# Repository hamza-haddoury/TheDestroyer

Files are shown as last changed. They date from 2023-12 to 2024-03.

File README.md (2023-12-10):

Logo Polytech Nice Sophia

# TheDestroyer
TheDestroyer est un projet Arduino réalisé dans le cadre de la formation de prépa intégrée de Polytech Nice-Sophia.
## Présentation
TheDestroyer est un tank miniature capable de se mouvoir et de tirer des projectiles.( voir le <a href="/Documentation/Cahier-des-charges.pdf">cahier des charges</a> )

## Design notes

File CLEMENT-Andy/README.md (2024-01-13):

# Dossier personnel de CLEMENT Andy sur le projet TheDestroyer
Vous trouverez ici le planning ainsi que les rapports de séance personnels concernant le projet Arduino.

## Planning 
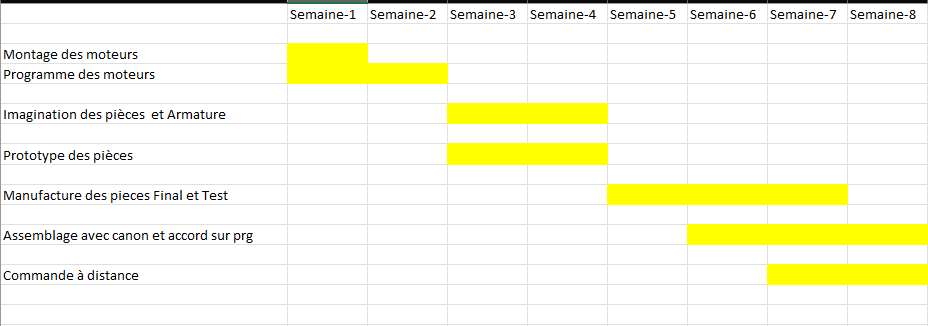
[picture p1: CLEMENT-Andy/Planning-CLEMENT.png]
Planning de CLEMENT Andy


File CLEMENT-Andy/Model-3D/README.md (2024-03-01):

<p>Vous trouverez les modèles 3D qui ont servi à la conception du tank.<br/>
Vous trouverez <a href="https://cad.onshape.com/documents/29475f88cb30b432ccc1cab9/w/a2ebf4db9098ca263dcf5bed/e/63d1c44178a9f2d052091fa9"> ici </a> le lien de partage Onshape qui vous permez de voir mon travail.</p>

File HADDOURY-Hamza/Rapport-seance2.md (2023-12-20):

L'objectif de la séance d'aujourd'hui était de modéliser les roues qui seront fixées sur les deux moteurs, de mettre à niveau l'alimentation des moteurs avec une source 5V dédiée, résoudre le problème lié à la vitesse d'un des moteurs et travailler sur la modélisation 3D de la partie supérieure du canon, capable de pivoter.

---

## Modélisation des Roues 

- Modélisationn des roues sur Onshape, conçues pour propulser la balle à travers le canon avec un espace dédié aux joints qui seront en contact avec la balle.
Mon Image

---

## Résolution des Problèmes de Moteurs :

- Un des moteurs ne tournait pas à plein régime comme le second.
- La résolution a été apportée en ajustant les connexions électriques et en recalibrant le code de contrôle des moteurs.

---

## Ajustements dans le Code Arduino 

- Des modifications ont été apportées dans le code Arduino pour garantir un contrôle équilibré et optimal des deux moteurs.

---

## Avancées sur la Modélisation 3D du Canon 

- Travail en cours sur la modélisation 3D de la partie supérieure du canon, qui aura la capacité de pivoter.

---

## Mise à Niveau de l'Alimentation 

- Pendant la séance, une alimentation 5V dédiée a été introduite pour les moteurs.
- Cette mise à niveau a été effectuée pour fournir le courant nécessaire aux moteurs afin de leur permettre de tourner à plein régime, comblant ainsi la limitation de courant de la carte Arduino.

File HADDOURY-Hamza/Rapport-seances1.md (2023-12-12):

### • Matériel recue
2 moteurs pour tirer les projectiles  
2 servomoteurs pour controler l'orientation du canon  

### • Montage Arduino
Attribution des broches appropriées de l'Arduino pour le contrôle des moteurs, avec un pont en H (L298N) pour gérer la polarité et la vitesse.  

Mon Image

### • Code de Contrôle des Moteurs
Développement d'un code Arduino permettant un contrôle de la vitesse (puissance de tir).

```
int enableMotor1 = 9;   

int motor1Input1 = 8;    
int motor1Input2 = 7;    

int enableMotor2 = 10;    
int motor2Input1 = 11; 
int motor2Input2 = 12; 

void setup() {
  // Configuration des broches en sortie
  pinMode(enableMotor1, OUTPUT);
  pinMode(motor1Input1, OUTPUT);
  pinMode(motor1Input2, OUTPUT);

  pinMode(enableMotor2, OUTPUT);
  pinMode(motor2Input1, OUTPUT);
  pinMode(motor2Input2, OUTPUT);
}

void loop() {
  analogWrite(enableMotor1, 200); 
  digitalWrite(motor1Input1, HIGH);
  digitalWrite(motor1Input2, LOW);

  analogWrite(enableMotor2, 150); // Valeur entre 0 (arrêt) et 255 (vitesse maximale)
  digitalWrite(motor2Input1, HIGH);
  digitalWrite(motor2Input2, LOW);

  delay(5000);

  // Arrêt des moteurs
  digitalWrite(motor1Input1, LOW);
  digitalWrite(motor1Input2, LOW);
  digitalWrite(motor2Input1, LOW);
  digitalWrite(motor2Input2, LOW);

  delay(2000);
}

```

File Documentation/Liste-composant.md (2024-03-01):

# Liste des composants éléctroniques utilisés: 
<ul>
<li>1 Carte Arduino Mega</li>
<li>2 motoréducteurs à courant continue</li>
<li>2 ponts en H ( L298N) </li>
<li>1 module Blutooth HC-05</li>
<li>1 batterie Lithium-ion de 7V</li>
<li>3 servos moteurs</li>
<li>2 moteurs à faible couple</li>
</ul>

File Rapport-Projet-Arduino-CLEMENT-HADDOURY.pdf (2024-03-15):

CLÉMENT Andy/
HADDOURY Hamza

# Rapport Projet Arduino: The Destroyer

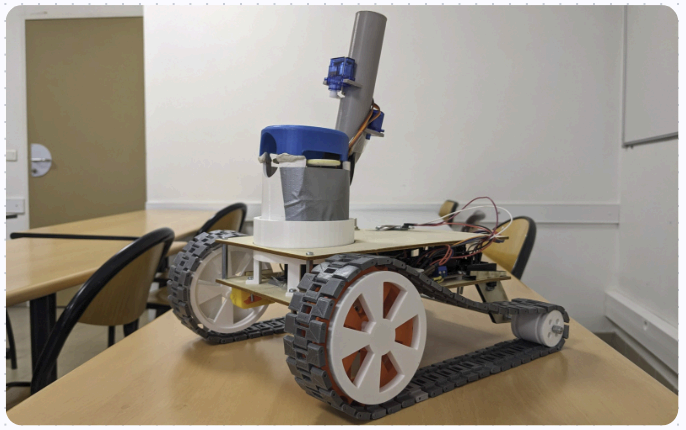
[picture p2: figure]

## Introduction

Ce projet à été réalisé dans le cadre de la formation de prépa intégrée de Polytech Nice-Sophia. Le but était de créer en 8 semaines un objet en utilisant des composants électroniques pilotables via une carte Arduino. Ce projet est une mise en situation (dans une moindre mesure) du métier d'ingénieur et permet donc de nous projeter dans notre futur métier. Pour le choix du sujet, nous voulions un objet qui se rapproche d’un jouet, il devait être simple d’utilisation et amusant, il nous est alors venue l’idée d’un tank télécommandable.

The Destroyer est un tank capable de se déplacer dans toutes les directions et tirer des balles en mousse via son canon intégré. Le tank est commandable à distance via une télécommande bluetooth ( ici notre téléphone portable) et fonctionne sur une batterie. Les commandes doivent être réactives pour assurer un contrôle en temps réel.
Pour créer un tel objet il nous fallait respecter quelques points.

Mobilité
- Intégrer deux moteurs pour entraîner les chenilles, se sont des roues motrices.
- Programmer les mouvements du tank (avancer, reculer, tourner).
Canon
Orientation du Canon:
- Intégrer un servo-moteur pour piloter l'orientation du canon.
- Programmer le contrôle de l'orientation via la télécommande. Fonctionnalité de Tir:
- Intégrer un mécanisme de tir (par exemple, un lanceur de projectiles).

- Programmer le contrôle du tir via la télécommande.

Alimentation
Batterie rechargeable assurant l'alimentation général du tank.

Châssis et chenille
- Concevoir et construire un châssis robuste pour protéger et transporter les composants.
- Imaginer les maillons de chenilles pour assurer la mobilité.
- Intégrer des phares LED pour une meilleure visibilité dans des conditions de faible luminosité.

Logement des éléments:
- Intégrer un support solide pour le canon, permettant une orientation précise.
- Prévoir un espace dédié pour la carte Arduino et les différents composants présents.
- Concevoir un compartiment pour la batterie, avec un accès facile pour la recharge.

Commande à distance
- Associer le code du véhicule avec un moyen de contrôle à distance ( Par Bluetooth)

## Notice d'utilisation

Le tank dispose d’un interrupteur pour la mise en marche et l’arrêt. Une fois allumé il faut associer le véhicule à la télécommande (smartphone utilisant l’application bluetooth electronics). Vous pouvez désormais diriger le tank à votre envie !

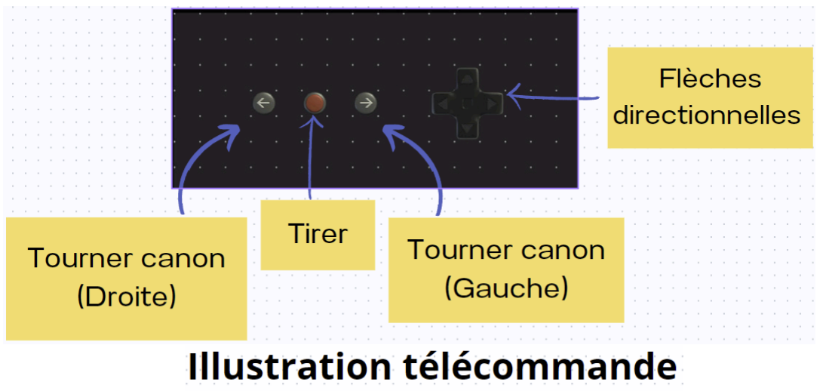
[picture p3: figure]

## Schéma électrique

Pour que le tank fonctionne correctement il a fallu câbler chaque composant correctement pour éviter toute panne. En effet les motoréducteurs et les moteurs à faible couple doivent être alimentés en 6V via des ponts en H qui sont eux-même alimentés via deux alimentations différentes, une servant à alimenter les portes logiques (5V) et une autre alimentant les moteurs ( allant jusqu'à 12V). La batterie ayant une tension de 7.46V, il nous était nécessaire d’avoir un contrôleur de tension pour avoir une tension de 6V dans le circuit. Tous les autres composants sont alimentés via la carte Arduino. On a donc deux circuits d’alimentation, une pour les ponts en H, une autre pour le reste des composants.

En somme le circuit contient:
1 Carte Arduino Mega, 2 motoréducteurs à courant continu, 2 ponts en H ( L298N), 1 module Bluetooth HC-05,1 batterie Lithium-ion de 7V, 1 Contrôleur de tension, 3 servomoteurs- SG90 (Chargeur), 2 moteurs à faible couple-MABUCHI RS 280 ( lanceur de balle).

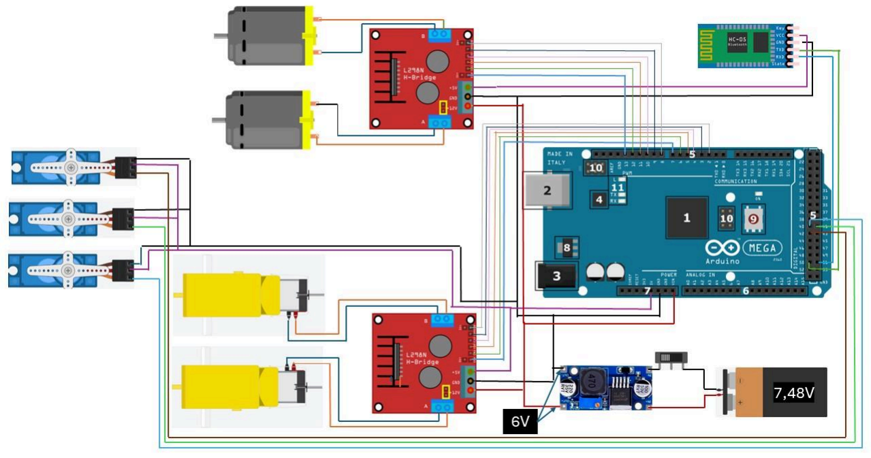
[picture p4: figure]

## Algorigramme

Chaque action du tank est reliée à une fonction pour simplifier l’écriture du programme. Chaque fonction est lancée si le caractère auquel il est associé est lu dans le buffer. Les caractères sont reliés à un bouton particulier sur la télécommande et sont envoyés à la carte si l’on appuie sur le bouton correspondant. ( à noter que les boutons associés à la direction renvoient ‘/’ s’il ne sont pas actionnés). L’algorithme est structuré comme tel:

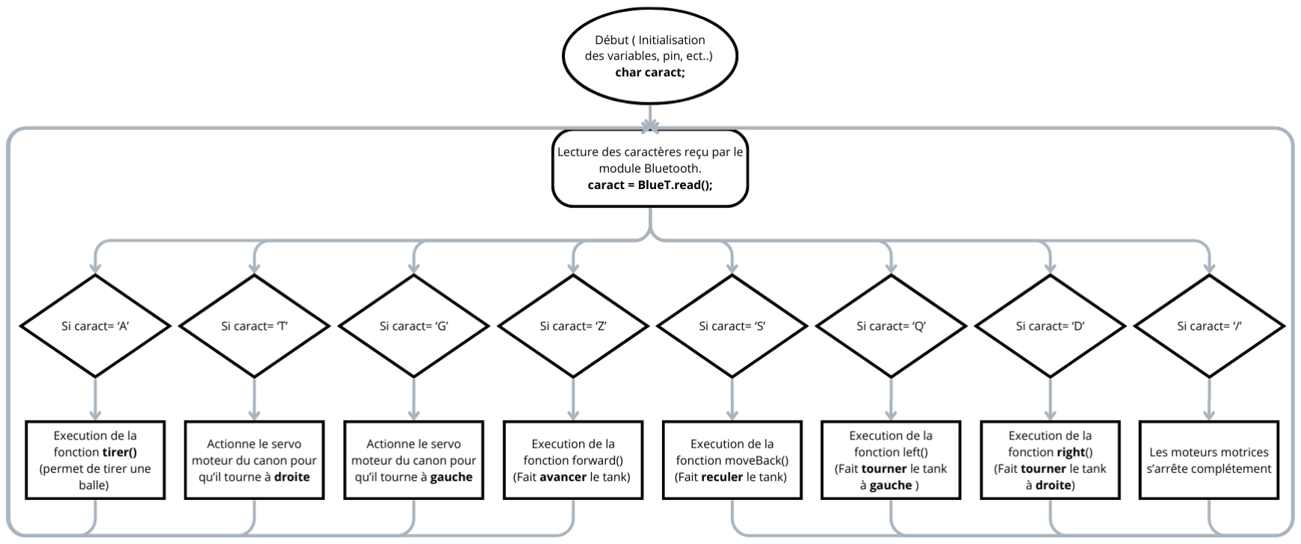
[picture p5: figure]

Toutes les fonctions mentionnées contrôlent la direction de rotation des moteurs ainsi que la puissance attribuée à chacun durant l’action. A noter que le programme n’utilise pas de ‘if()’ pour décider de quelle fonction appeler mais utilise les instructions ‘switch()’ et ‘case’.

## Coût du projet

Pour estimer le coût de construction du projet nous comptons les coûts d’achat du matériel ( Carte arduino, batterie, moteurs, bois, ect..) ainsi que le nombre d'heures de travail effectué sur le projet. Pour calculer le coût du travail nous sommes partis sur la base d’un salaire brut annuel de 38k € pour 1600h de travail ( 23.75€/ 1h) . En comptant les 8 séances dédiées au projet et le travail personnel , nous sommes à (38 h+30 h = 68 h) heures de travail, ce qui nous revient à 1615€ pour le coût de la main d'œuvre. Pour le coût du matériel, nous avons cherché les prix sur Amazon ou encore AliExpress. Nous avons essayé de prendre les prix les plus bas pour limiter les coûts( voir le détail des prix en dessous). Au final le projet à coûté 1678.5€.

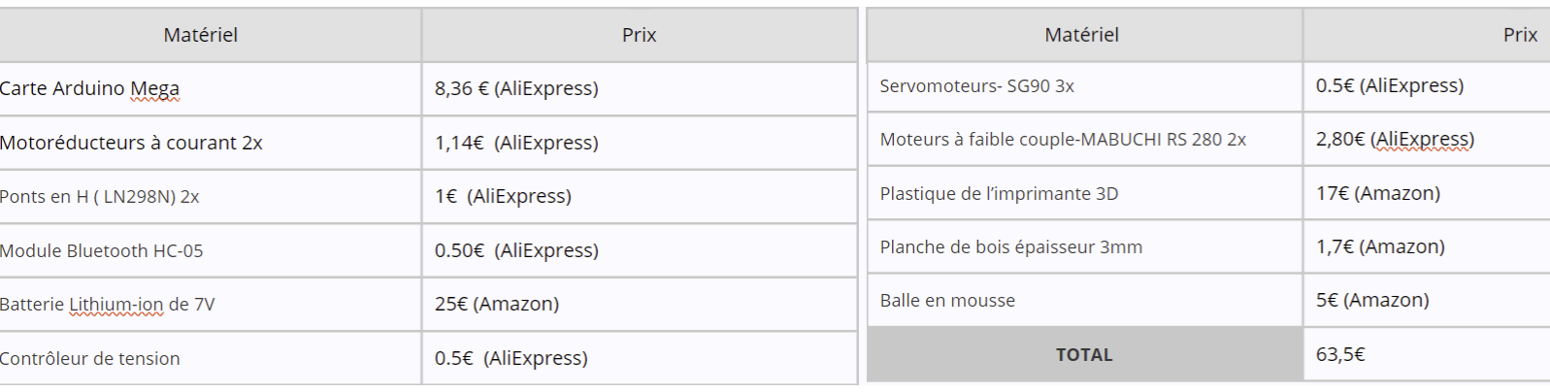
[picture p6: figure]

## Problèmes rencontrés

Problème Châssis et chenille:

Lors des essais de roulage, les chenilles sortaient de leur trajectoire et déraillaient. Ce problème était dû aux chaînes qui n'étaient pas assez tendues parce que les roues arrière s'affaissaient à cause du poids trop important du tank, de plus les roues motrices du tank avaient également un carrossage négatif ce qui empêchait les chenilles de maintenir une trajectoire droite. Pour régler ce problème, nous avons décidé d’ajouter une tige filetée entre les deux supports de roue arrière pour éviter que les roues ne s’affaissent. Pour les roues avant nous avons ajouté de la pâte à fixe pour combler le jeu entre le châssis et les moteurs.

On a également dû changer de type de cartes passant d’une carte Uno à une carte Mega. Puisque nous avions besoin de deux ponts en H ( L298N), nous avions besoin de plusieurs ports PWM, malheureusement, la carte Uno n’en possédait pas assez, c’est pourquoi nous sommes passés sur une carte Mega.

Problèmes Canon:

Lors des phases d'essai, nous avons identifié un problème majeur lié au chargement manuel des balles entre les moteurs du canon. Nous avons constaté que cette opération devait être effectuée manuellement à chaque fois qu'un tir était envisagé. De plus, le fait que la balle ne pouvait pas rester en place entre les moteurs en attente d'être tirée était un inconvénient majeur. Les moteurs manquaient de couple pour maintenir la balle en place, ce qui entraînait un blocage.

Pour remédier à cette problématique, nous avons élaboré un système de recharge. En activant la commande de tir, notre système de chargeur permet désormais le passage automatique d'une balle entre les moteurs du canon. Cette amélioration nous permet de tirer jusqu'à cinq balles consécutivement sans avoir besoin d'une intervention manuelle pour charger chaque projectile.

Après l’assemblage avec le châssis, les moteurs chargés de propulser la balle consommaient excessivement de courant, laissant peu de ressources aux moteurs du chargeur. Cette situation a entraîné plusieurs dysfonctionnements et bugs, dans certains cas après avoir été activés les moteurs ne s'arrêtaient plus, compromettant ainsi le bon fonctionnement global du système.

De plus, lors de la sortie de la balle du chargeur en vue de son tir, des incidents se sont produits. Parfois, la balle rebondissait, échappant ainsi à l'axe des roues du moteur destiné à la propulsion. Dans certains cas, elle était éjectée sans être correctement projetée, tandis que dans d'autres, elle restait coincée, bloquant les balles suivantes.

## Planning

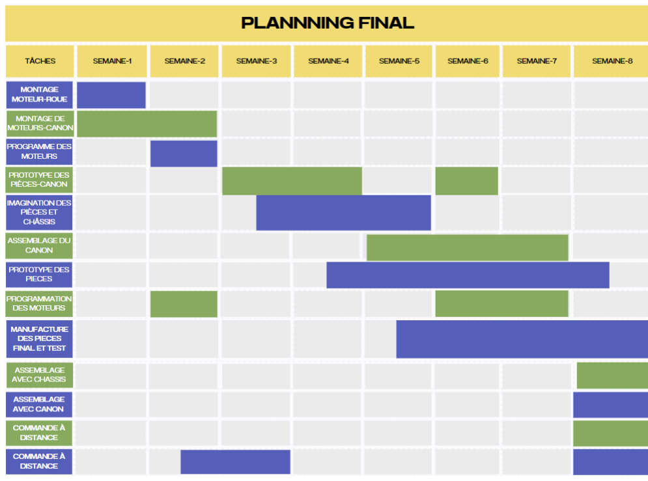
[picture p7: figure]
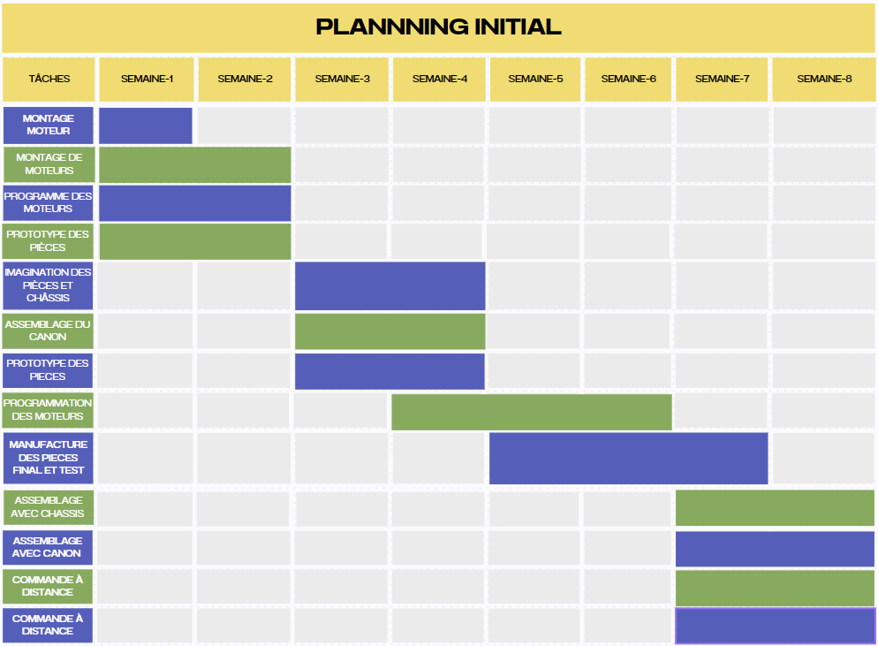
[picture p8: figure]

Avant de commencer le projet, nous avions créé un planning ( diagramme de Gantt) qui organisait notre travail et ainsi assurait que l’on rend le projet à temps et fonctionnel. Initialement nous avions défini découpé et attribué une période chaque phase du projet, cependant durant le projet, on s’est aperçu que certaines tâches demandaient plus de temps que prévu. En comparant les deux emplois du temps, on se rend compte que les tâches effectuées en début de cycle respectaient bien le temps prévu mais que certaines tâches ont demandé plus de temps que prévu. La conception et la réalisation des pièces ont demandé plus d’effort que prévu ce qui a empiété sur le temps consacré à l’assemblage.

## Conclusion

En conclusion sur ce projet nous avons produit un châssis pouvant accueillir des composants électroniques ainsi qu’un capot en bois sur mesure, des roues crantées adaptées aux motoréducteurs pour entraîner les chenilles, un système de direction et des commandes simples d’utilisation. Pour le canon, nous avons développé un mécanisme de tir permettant de tirer jusqu'à cinq balles coup par coup sans nécessiter d'intervention manuelle entre chaque tir, grâce à un système de rechargement automatique. De plus, le canon est également doté d'une capacité d'orientation. Les phares initialement prévus n’ont pas été intégrés par faute de temps.

Si nous avions encore 9 séances supplémentaires, nous développerions la partie esthétique du tank en peignant les pièces et en concevant un revêtement travaillé et agréable à l'œil. Nous pourrions intégrer les phares comme initialement prévu pour avoir une bonne vision la nuit et peut-être même ajouter une caméra embarquée qui nous transmettra en temps réel les images perçues. On pourrait également développer une application exportant la possibilité de contrôler le tank via d'autres périphériques ( Iphone ou encore PC) car actuellement, seulement un smartphone android peut le piloter.

Ce projet nous a permis de nous mettre en situation et de nous projeter dans le métier d’ingénieur. Il nous a également appris à faire preuve d'inventivité, d’esprit d’équipe et nous a poussé à chercher des solutions pour régler les différents problèmes rencontrés.

## Bibliographie

Site d’aide au montage:

https://www.adafruit.com/product/3777https://arduino-france.site/moteur-cc/https://docs.arduino.cc/learn/built-in-libraries/software-serial/https://arduino-france.si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

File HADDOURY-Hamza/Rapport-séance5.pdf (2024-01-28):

## Rapport séance 5

Objectifs de la Séance:
L'objectif principal de la séance était de modéliser les différentes pièces du canon. Ces pièces comprennent le support du cylindre pour les moteurs, le cylindre lui-même, le support des moteurs à l'intérieur du cylindre, et enfin le canon.

Support du cylindre :

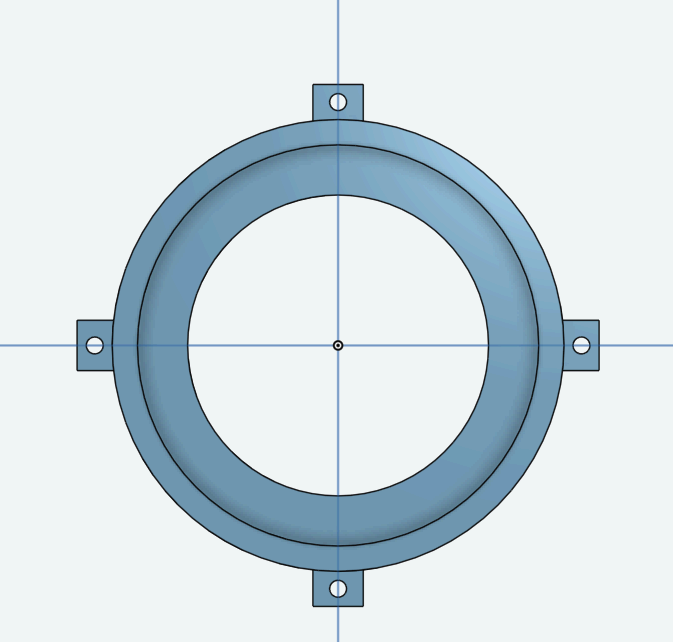
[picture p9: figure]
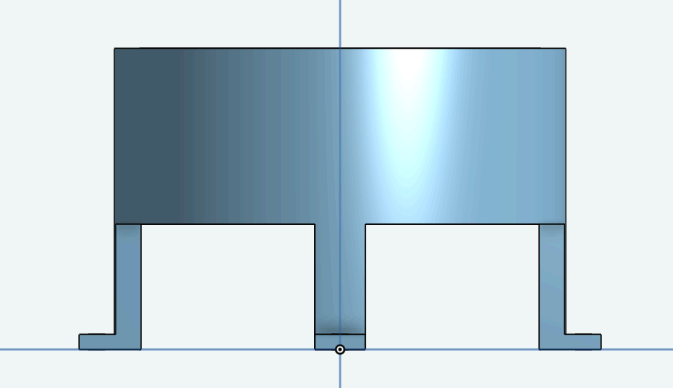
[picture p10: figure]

vue de face | vue de haut

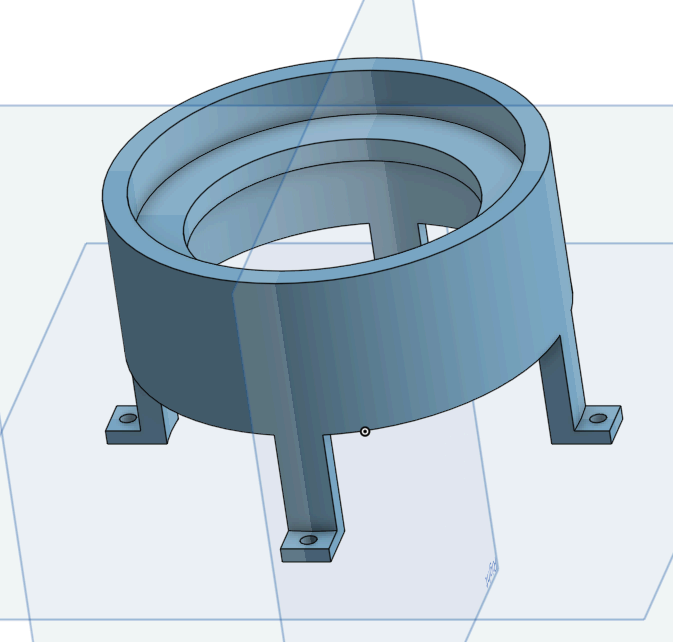
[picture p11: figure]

Le support sera fixé au châssis et à l'intérieur de lui se trouvera le servo moteur pour orienter le cylindre.

Cylindre et canon :

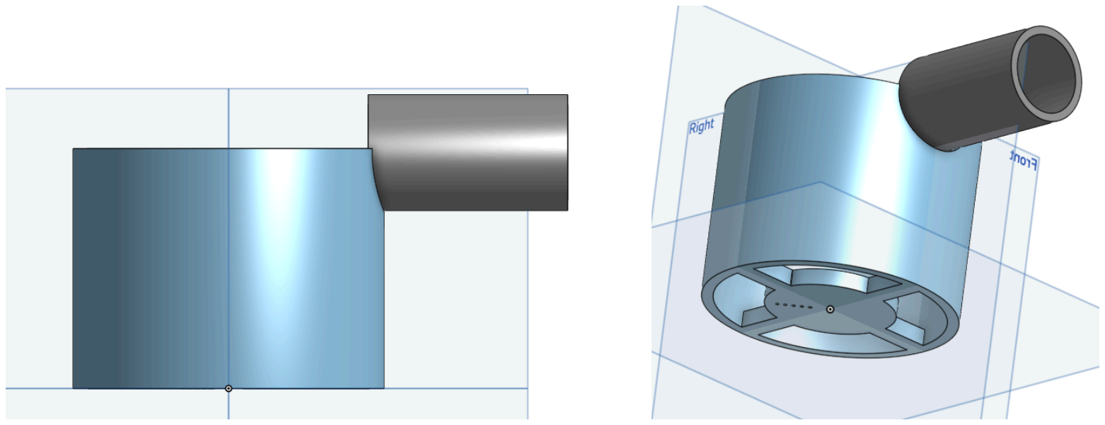
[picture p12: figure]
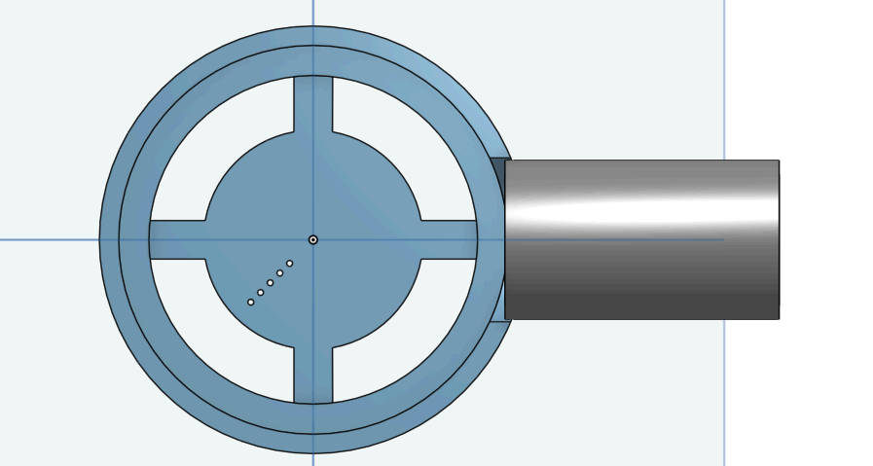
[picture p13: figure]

vue de haut | vu de face

Le cylindre sera fixé au servomoteur et abritera les deux moteurs qui propulseront le projectile à travers le canon.

Support des moteurs

pour réaliser cette pièce je me suis inspiré de la maquette en carton que j’ai faite pendant la séance 4

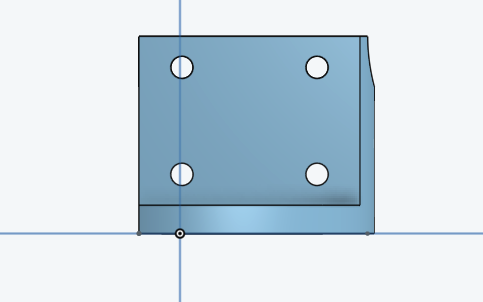
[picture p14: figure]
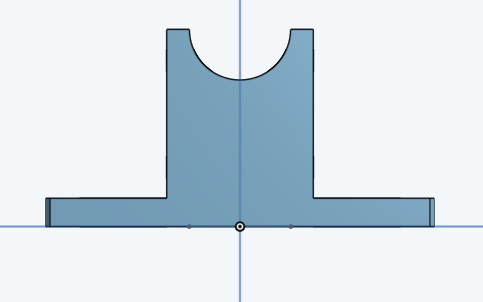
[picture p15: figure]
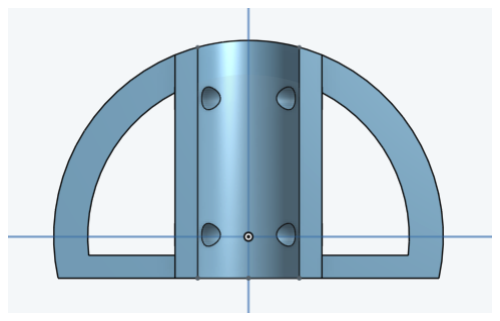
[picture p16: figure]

vue de haut | vue de face | vue de droite

Assemblage de toute les pièces

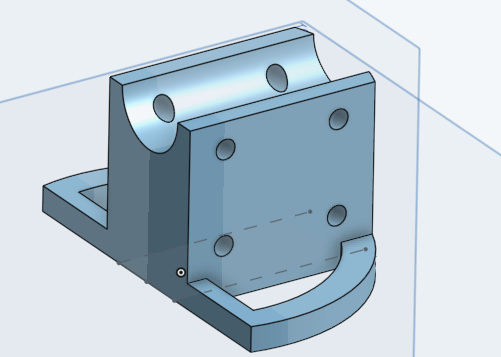
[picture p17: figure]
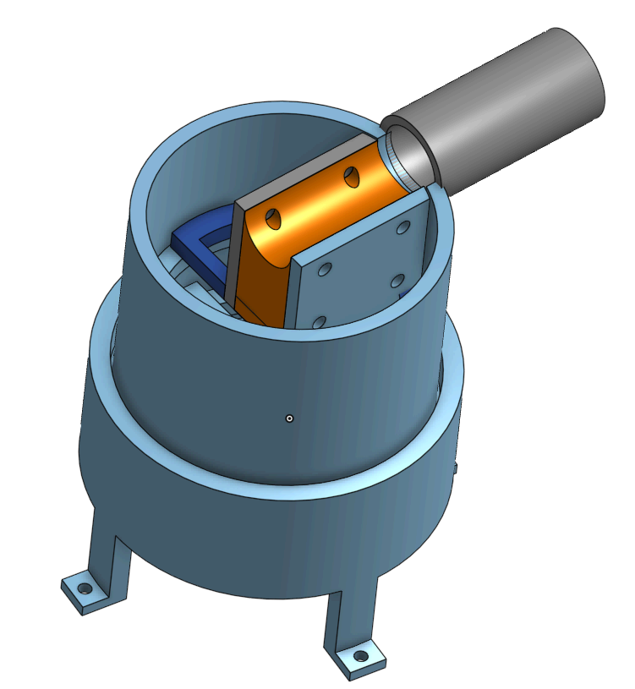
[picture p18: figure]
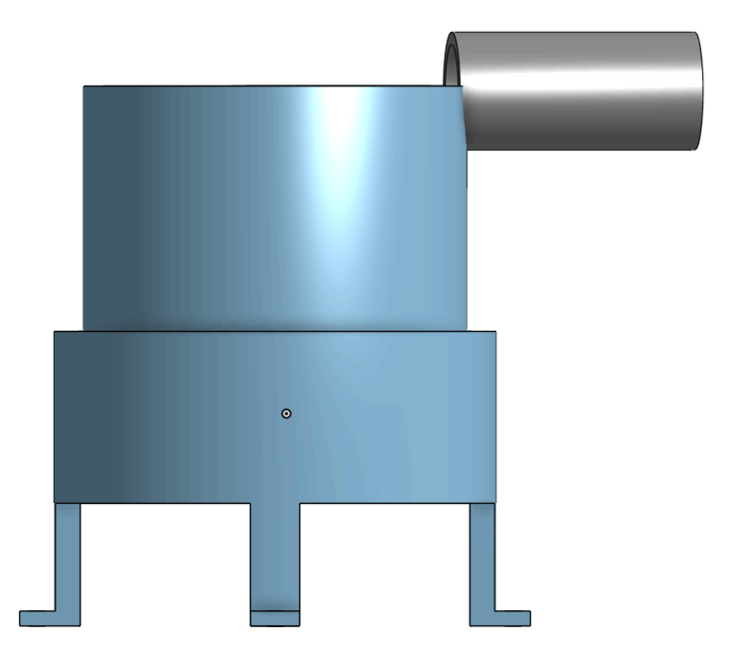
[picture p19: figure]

Malheureusement durant cette séance je n’ai pu imprimer que le support des canons par manque de temps. En y fixant les moteurs, j’ai réalisé que mes mesures n'étaient pas assez précise car l’espace entre les roues des moteurs était assez important et ne permettait aucun frottement avec la balle afin d'être projeté.

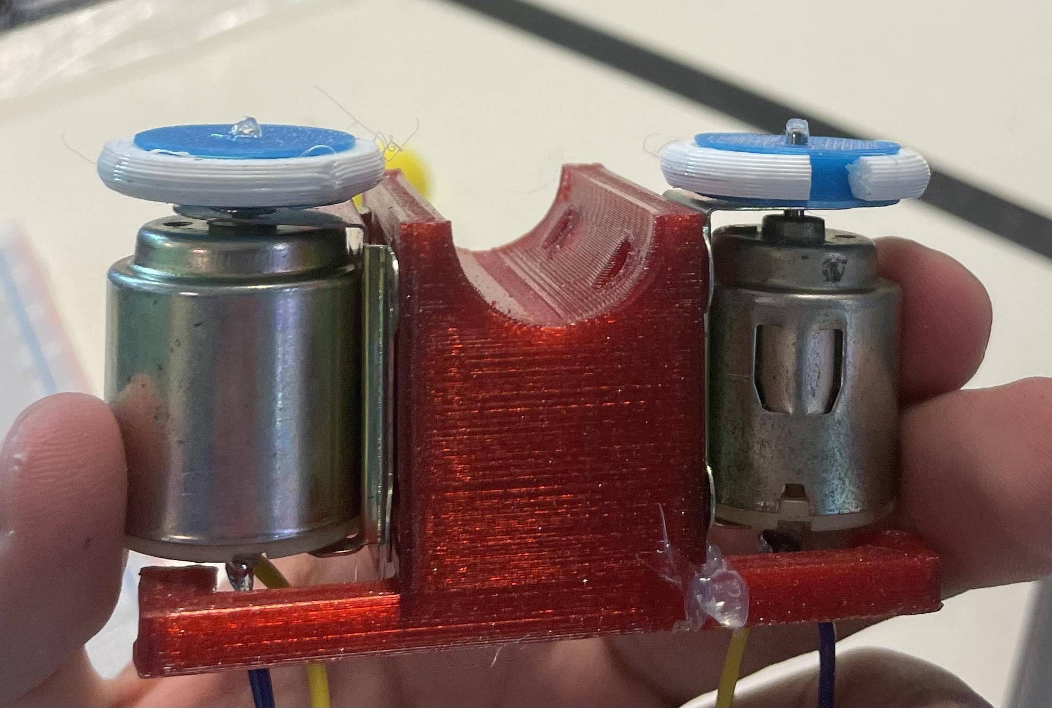
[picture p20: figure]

pour la séance prochaine je compte assembler toute les pièces et imprimer de nouvelle roue avec un diamètre plus important que les dernières afin d'avoir une meilleure adhérence quand on tire les balles

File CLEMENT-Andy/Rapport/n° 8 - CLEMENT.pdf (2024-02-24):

CLEMENT Andy | Polytech Nice-Sophia Peip2

## Rapport de Séance n°8

## (Semaine du 19 Février)

### Travail Personnel:

J’ai codé le programme de pilotage du tank. Avec le peu de temps qui nous restes j’ai décidé d’abandonner le contrôle via un joystick virtuel pour le remplacer par un contrôle via des boutons directionnels. En effet je n’arrivais pas à relever les coordonnées du joystick réceptionnées par le module Bluetooth. J’ai opté pour solution plus simple à mettre en place. Chaque bouton directionnel est relié à une direction( en avant, en arrière, gauche droite) ce qui assure une maniabilité facile est sûr. Le programme gère la rotation du tank ainsi que ces déplacements, la puissance fournie aux moteurs est maximale.
On a 4 fonctions:
-forward(): rotation des moteurs pour que le tank avance.
-moveBack(): rotation des moteurs pour que le tank recule. -right(): rotation des moteurs pour que le tank tourne à droite.
-left(): rotation des moteurs pour que le tank tourne à gauche

Le code relie un caractère à une fonction. Chaque caractère est relié à un bouton de commande. Une fois la configuration Bluetooth terminé j’ai testé le code et les déplacements du tank, tout fonctionne correctement. Cependant lors des déplacements, l’une des chenilles se délogeait, j’ai donc réimprimé une roue qui convenait mieux et remplacé l’ancienne par la nouvelle.
J’ai également découpé un toit pour couvrir le câblage du tank. Il sera fixé à l’aide d’entretoises en métal retenu avec des vis.

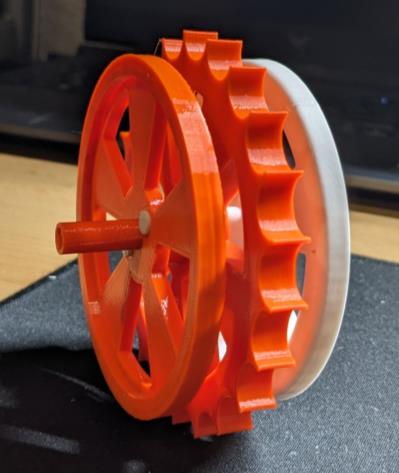
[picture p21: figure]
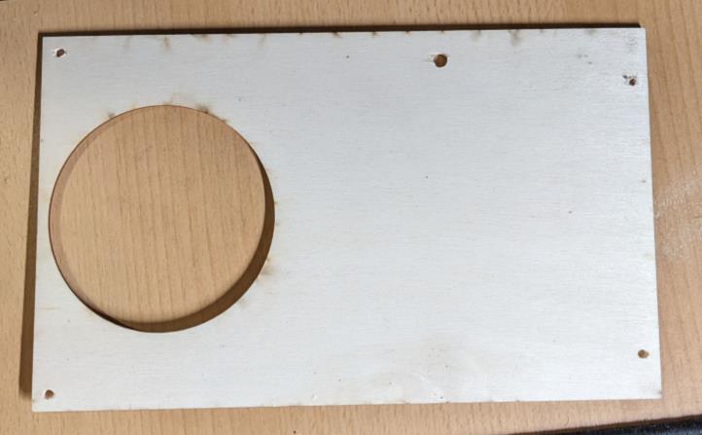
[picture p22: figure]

Avec mon collègue nous avons commencé l’assemblage de nos 2 parties du tank. J’ai fait les raccordements du canon et des servo-moteurs avec la Arduino Mega. Le nombre de port étant conséquent, il n’y avait pas de problème à ce niveau-là.

Nouvelle roue | Toit/capot du tank

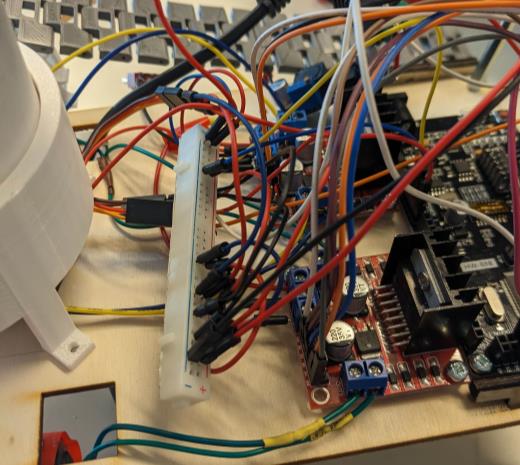
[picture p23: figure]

Connexion des grounds et de l’alimentation Arduino

Travail de la séance:

Durant cette séance j’ai revu les branchements et raccourci les câbles pour que le câblage soit plus propre. J’ai repositionné l’interrupteur ainsi que le potentiomètre pour laisser de la place aux câbles. J’ai également percé des trous sur le toit et le châssis pour que les deux soient bien fixés par les entretoises. J’ai usiné les vis servant à raccorder les parties.
J’ai fixé le canon sur le châssis à l’aide vis et relier tous les moteurs à la carte. Le toit du canon devra être revue car elle ne peut pas s’emboiter correctement.
Pour connecter les grounds et l’alimentation 5v de l’Arduino j’ai utilisé une partie de bread board car la confection d’une carte pcb sur-mesure prendrait trop de temps.
J’ai testé les tensions aux bornes des ponts en H et tout est normal, il n’y a pas de chute de tension.

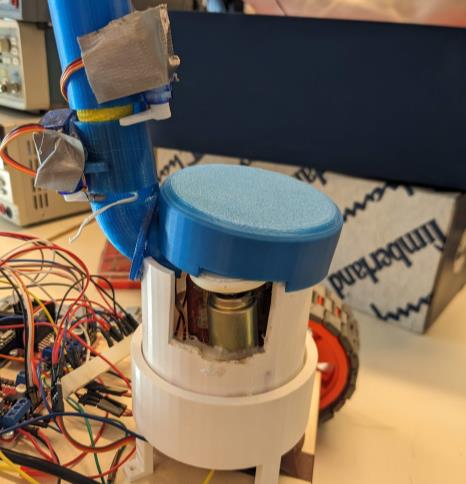
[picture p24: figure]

Aperçu du canon


Entretoise ( ici la vis n’a pas été usinée)

connexion


Aperçu du tank

Tige filetée

Une fois que tout a été minutieusement connecté, j’ai testé le câblage avec les différents programmes pour vérifier qu’il n’y avait pas de problème. RAS.
Avec tous les éléments présents dans le tank, le tank commence à devenir lourd. Ce poids important fragilise l’arrière du tank notamment les pièces qui supportent les roues. J’ai donc pris une tige filetée de 4 mm de diamètre qui reliera les 2 roues. Cette tige filetée servira de renfort et de bar « anti-écartement » pour les 2 supports de roue arrière. Ainsi l’arrière du tank sera plus stable.

Il nous reste quelque petit ajustement pour que le tank soit totalement opérationnel et enfin finir totalement notre projet.

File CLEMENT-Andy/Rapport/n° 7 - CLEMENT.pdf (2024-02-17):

CLEMENT Andy | Polytech Nice-Sophia Peip2

## Rapport de Séance n°7

## (Semaine du 12 Février)

### Travail Personnel:

J’ai revu les branchements pour que le tank puisse fonctionner sur batterie et être allumé par un interrupteur. J’ai également rebranché le module Bluetooth pour attaquer la phase finale du projet.

### Travail de séance:

J’ai assemblé et collé les parties de la roue que j’ai imprimées la semaine dernière pour que la roue soit bien solide et puisse être opérationnelle. J’ai comblé les trous de fixation avec de la pâte à fixe et de la colle.
J’ai également revu la disposition des composants à la surface du châssis pour accueillir le canon de mon collègue. En effet, dans la disposition précédente, le canon se trouvait à l’arrière du tank, ce qui n’était pas cohérent avec le modèle de char Renault. La nouvelle disposition positionne le canon à l’avant, ainsi les ponts en H qui devaient se trouver à l’avant se trouvent à l’arrière.
Après avoir consulté mon collègue sur la disposition des composants, je suis allé percer des trous de 3 mm dans le châssis pour fixer les composants à l’aide de vis.
Pour continuer, j’ai fixé la batterie en dessous du châssis à l’aide de scotch double face. Cette solution semble fonctionner pour le moment. J’ai également réglé le potentiomètre de l’alimentation pour avoir une tension de 6V afin d’alimenter correctement le circuit.


Batterie sous châssis

CLEMENT Andy | Polytech Nice-Sophia Peip2


Arduino MEGA

Durant cette séance, nous nous sommes rendu compte que le nombre de port PWM sur la carte Arduino Uno était trop faible pour nos besoins, en effet nous avons besoin d’alimenter et de piloter 2 ponts en H, impossible avec le nombre de port PWM que cette carte nous fournissait. On s’est donc tourné vers une carte Arduino Mega qui comporte plus de ports PWM ( 15 au lieu de 6). Le nombre proposé est plus que suffisant. Cette carte peut fonctionner avec une alimentation de 6V ce qui est la puissance délivrée avec la batterie.


Pour rendre le câblage plus propre, j’ai raccourci les câbles d’alimentation des moteurs. De plus lors des tests, le branchement de mon interrupteur s’est rompu. J’ai donc refait la connexion pour qu’il soit de nouveau opérationnel.

Tank monté sur batterie

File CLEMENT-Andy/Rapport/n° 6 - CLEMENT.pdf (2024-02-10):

CLEMENT Andy | Polytech Nice-Sophia Peip2

## Rapport de Séance n°6

## (Semaine du 5 Février)

### Travail Personnel:

Suite à la dernière séance j’ai redimensionné les pièces. En effet sur la roue motrice, l’assemblage était difficile à cause des emboitements trop serrés. J’ai donc agrandi les emplacements d’emboitement(7 mm de diamètre au lieu de 6 mm). De plus l’espacement entre les dents n’était pas assez important mais cela se jouait sur quelques millimètres. J’ai donc réduit le nombre de dents pour augmenter la distance entre chacune.


Roue en trois parties


Pièces après
nettoyage


Pièces avant nettoyage

### Travail de séance:

Après assemblage et test des pièces, il y a du jeu sur la roue en trois parties dû à l’augmentation du diamètre des trous pour l’emboitement. La nouvelle répartition entre les dents fonctionne mieux que la précédente. Le problème de jeu peut se régler avec de la colle . Puisque la roue est en trois parties, il est facile de remplacer la partie obsolète par une autre.

Bien que l’impression des trois parties semble correcte, celle de la roue arrière était moins propre. En effet les zones où il y avait des supports étaient mal ressortie. J’ai donc nettoyé et poncé la pièce pour avoir un résultat plus net.

CLEMENT Andy | Polytech Nice-Sophia Peip2


Châssis avec roues et chenilles

De plus en fin de séance j’ai essayé de brancher tout le système du tank sur batterie mais la carte Arduino ainsi que le pont en H n’étaient pas alimentés. Le câblage devra être revue et mis au propre pour enchainer sur les tests Bluetooth.

J’ai dû ressouder une connexion du moteur qui s’était endommagé. J’ai également positionné la batterie en dessous du châssis mais elle est trop lourde pour être maintenue par du ruban adhésif, il faudra trouver une solution.
J’ai réajusté quelques pièces avec des ciseaux à bois. J’ai ensuite assemblé toutes les pièces ( châssis, Roues, chenilles) et obtenue le résultat suivant.

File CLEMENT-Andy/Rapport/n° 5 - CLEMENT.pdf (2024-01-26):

CLEMENT Andy | Polytech Nice-Sophia Peip2

## Rapport de Séance n°5

## (Semaine du 22 Janvier)

### Travail Personnel:

Comme précisé dans le dernier rapport de séance ( cf. rapport n°4), j’ai avancé la modélisation des pièces du tank. J’ai retravaillé les dimensions des lames arrière pour qu’elles répondent mieux à leur fonction, c’est-à-dire maintenir les roues arrière au même niveau que les roues avant. J’ai ajouté un trou de 5mm ( qui pourra être ajustée en fonction du diamètre de l’axe) pour le passage de l’axe de rotation. J’ai aussi arrondi un angle pour que la pièce soit plus jolie.


Esquisse d’une lame
(vue de droite)


Esquisse du châssis
(vue du dessus)

Pour les fixer, j’ai donc retravaillé le châssis pour qu’elle puisse accueillir les lames. J’ai utilisé le même principe que pour les cales de moteur, je vais emboité les lames dans le châssis à travers des fentes qui feront 40mm de longueur et 4mm d’épaisseur. Pour éviter qu’elles ne remontent à cause du poids du tank, je vais les fixer avec une tige en bois qui se positionnera en dessous du châssis. Cette tige passera à travers des fentes creusées dans les lames.


Châssis extrudé

Lame extrudée


Esquisse du châssis
(vue du dessus)

### Rectification:

Après un passage au Fablab, j’ai réimaginé l’emplacement des lames. En effet la visserie mis à disposition ne permet pas de faire un axe long. J’ai donc décidé de rapproche les lames pour qu’elles se chevauchent et créer une seul et même pièce. Les lames se feront une épaisseur de 5mm. J’ai retravaillé le châssis pour accueillir les lames. L’encoche fera donc 10mm d’épaisseur. Cet assemblage sera aussi solide que le précèdent


Châssis extrudé

J’ai également modélisé les roues motrices qui seront positionnées à l’avant. Elles entraîneront les chenilles que j’ai récupérées sur un ancien projet. Les roues motrices (à l’avant) seront composées d’une roue crantée qui se situe entre 2 disques. La roue crantée a pour rôle d’entrainer la chenille via des trous prévue à cet effet. Les 2 disques serviront de guide en maintenant les chenilles alignées à l’aide de crans pour éviter qu’elle ne déraille.
Ces roues viendront se fixer directement aux moteur DC grâce à l’emplacement prévue à cet effet. Ces roues ont un diamètre de 90mm une épaisseur de 9mm.
Pour que l’impression soit plus rapide, J’ai essayé d’enlever le plus de matière possible en dessiner des roues à rayon pour limiter la quantité de plastique utilisée ( moins de support), Je les ai ensuite fixés à l’aide de vis et d’écrous.


Esquisse de la roue
(vue de gauche)


Esquisse de la roue arrière (vue de gauche)


J’ai également modélisé la roue arrière. Contrairement à la roue avant, la roue arrière n’as pas de crans, elle possède des butées pour éviter que la chenille ne déraille. Ces roues se fixent à l’aide d’une tige en métal qui va traverser les lames. Ces roues seront relativement petites puisqu’elles font 35mm de diamètre . Elle possède des motifs pour limiter la quantité de plastique à l’impression, ici des cercles. Aux vues du faible diamètre de la roue, ces cercles ne devaient pas être trop petits pour éviter que le centre ne se désolidarisent, c’est pourquoi ces cercles font 6 mm de diamètre, elles sont au nombre de 4 pour les mêmes raisons.


Roue arrière extrudé

Roue extrudée


Esquisse de la roue arrière (vue de face)

### Rectification:

Après une visite au Fablab pour prendre connaissance de la visserie et quelque conseil auprès des professeurs, j’ai remarqué que la roue Motrice était compliquée à modéliser. Elle allait nécessiter beaucoup de support et le rendu ne serait pas terrible. J’ai donc coupé la roue en 3 partie distincte, le tout relier par 2 colonnes pour les solidariser. J’ai mis de la colle pour les emboiter et qu’elle reste ensemble. En plus de réduire le temps d’impression, l’impression nécessite moins de plastique. Afin de tester la roue, j’ai lancé une impression pour rectifier la pièce s’il y a besoin.


Partie 1 de la roue | Partie 2 de la roue | Partie 3 de la roue


Roue assemblée

J’ai aussi modélisé la partie supérieure du tank pour pouvoir y accueillir le canon modélisé par mon collègue. Le canon sera accueilli dans un cylindre, je vais donc laisser un cercle de diamètre 120mm pour le canon. Cette partie du châssis se positionnera au-dessus de la première planche est sera vissé à des supports (sous forme de cylindre) qui reliront les 2 planches.


Esquisse châssis haut
(vue du dessus)


Après avoir modélisé toute ces pièces, je les ai assemblés pour avoir un rendu virtuel de ce que pourrait donner le tank. Je suis allé dans l’assembleur et assemblé toutes les pièces avec les liaisons correspondantes. J’obtiens ceci:


Tank
(Vue de droite)

Châssis extrudé


Tank
(Vue ¾ face)


Lame du châssis

### Contenue de la séance:

J’ai testé les roues avant pour voir si les chaînes ne rencontrent pas d’obstacle dans leur progression. Les chaînes de rencontre pas d’obstacle ce qui était le résultat espéré. Les crans des roues sont trop peu espacés car on remarque du jeu dans les chenilles. Il faudra réimprimer des roues avec des crans plus espacés.

Après avoir retravaillé le châssis, j’ai refait des découpes à la découpeuse laser dans du bois de 3mm. J’ai également découpé les lames arrière avec du bois de 5mm pour que l’axe soit bien maintenu et stable. L’axe sera une vis de 650mm maintenue par des écrous, elle servira aux roues arrière du tank.
En mesurant les chaînes, j’ai remarqué que mes lames en bois aller être trop longue, j’ai dû
de nouveau modifier les mesures pour qu’elles respectent les dimensions de la chaîne. Au lieu d’avoir un angle de 145°, elles possèdent un angle de 135° ( cf. esquisse des lames). J’ai donc recoupé des lames en bois.

J’ai ensuite assemblé les différentes parties du châssis ainsi que les roues et les moteurs pour voir le rendu que j’allais obtenir. Les lames ont été fixé avec de la colle, en plus des embouts en bois. Après l’assemblage des différentes pièces, j’ai constaté que les roue arrière et avant sont décalées d’environ 1-2mm, ce qui est un vrai problème. Pour remédier à ça il faudra couper une partie de l’axe des roue motrices car elles sont trop longues.


Tank monté


Potentiomètre et soudure

J’ai ensuite soudé les connexions de la batterie lithium au potentiomètre pour alimenter le tank. Pour rappel, la batterie sera positionnée sous le châssis pour maximiser la place au-dessus.
J’ai donc coupé des câbles noir et rouge et commencer à souder au endroit approprié. J’ai également pris un interrupteur qui nous servira à la mise en tension du tank lorsque l’on voudra sans avoir à débrancher la batterie. Je n’ai pas pu terminer la soudure de l’interrupteur en question.

A la prochaine séance, nous devrons essayer de terminer l’aspect esthétique du tank, imprimer les deux autres roues ainsi que certaine maille de la chenille qui sont endommagé pour enfin terminer la partie Bluetooth.

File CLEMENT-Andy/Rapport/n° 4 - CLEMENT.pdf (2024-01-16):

CLEMENT Andy | Polytech Nice-Sophia Peip2

## Rapport de Séance n°4

## (Semaine du 14 Janvier)

### Travail de la séance:

Depuis la dernière séance, l’un des fils de connexions de l’un de mes moteurs s’est cassé dans le pont en H. J’ai dû réparer cette casse en dénudant de nouveau mon câble et en le réétamant. J’en ai profité pour vérifier les liaisons de tous les câbles afin de prévenir de futures casses. Les câbles sont encore longs, il faudra les raccourcir pour le montage final avec toutes les pièces mais cela se fera à la fin. J’ai également ajouté du scotch isolant au niveau du moteur sur les connections pour les protéger des mouvements.


Liaisons moteur renforcées


Prototype assemblé

La semaine dernière j’ai également commencé à produire les pièces qui allait composer le châssis du tank. J’avais fait découper au laser des cales en bois pour soutenir les moteurs sous le châssis afin de conserver le maximum de place sur la plateforme en bois. Cependant je n’avais pas modélisé les trous qui allait servir au passage des vis. J’ai donc placé des repères sur les cales pour percer des trous de 3,5 mm pour le passage des vis. Pour placer les repères j’ai colorié le passage de vis d’un moteur pour l’utiliser comme
« tampon » sur l’une des cales et ainsi avoir la cale marquée par l’empreinte du moteur. J’ai mesuré la position du point obtenue et reporté la mesure sur les autres cales. Les passages de vis ont été fait à l’aide d’une perceuse et d’un foret à bois.
J’ai enfin pu assembler les pièces pour avoir un rendu plus concret de la maquette.


Dessous du châssis en bois avec emplacement prévue pour la batterie (crayon)

CLEMENT Andy | Polytech Nice-Sophia Peip2

Suite à ça, j’ai continué la modélisation de l’arrière du tank. J’ai pensé à un système qui permettrait de faire passer une tige en métal qui fera office d’axe de rotation pour les roues arrière. Cette tige passera entre 2 paires de lames pour être soutenu et maintenir l’indépendance des roues arrière. Pour fixer ces colonnes j’ai pensé au même système de soutien que les cales, c’est-à-dire des emboitements avec la plaque du châssis. Je pense faire ces pièces en bois de 3mm d’épaisseur et découper les lames à la découpeuse laser.


4 lames de support pour les tiges


Potentiomètre

Concernant l’alimentation, il nous faut une batterie assez puissante pour alimenter les moteurs. Les moteurs DC ont besoin d’une tension maximale de 6V pour fonctionner. Il nous faut donc une batterie délivrant au moins cette tension. J’ai donc reçu un kit de batterie rechargeable qui délivre 8 V. J’ai aussi reçu une pièce qui fait office de potentiomètre pour avoir une tension de 6V dans le circuit. Ce kit batterie sera placé en dessous de la plateforme. Je n’ai pas encore fait les raccords électriques, cela fera l’objet de la prochaine séance. Il faudra aussi ajouter un interrupteur pour mettre hors tension la machine.


Puisque le projet demande encore des pièces à manufacturer, je vais avancer la modélisation des pièces en travail personnel pour être dans les temps et respecter le planning. Il me faut modéliser les roues ainsi que les chenilles. Les roues avant seront plus grosse que les roues arrière pour imiter l’apparence d’un char Renault FT17

Kit batterie

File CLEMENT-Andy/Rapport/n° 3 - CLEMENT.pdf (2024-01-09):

CLEMENT Andy | Polytech Nice-Sophia Peip2

## Rapport de Séance n°3

## (Semaine du 8 Janvier)

### Travaille effectué durant les vacances de Noël:

- Mise en fonction du HC-05 et configuration du Bluetooth. J’ai réussi à configurer le module Bluetooth. Le problème venait d’une mauvaise connexion entre le TX et RX du module et la carte Arduino. Il ne me reste plus qu’à savoir extraire les coordonnées X-Y renvoyé par le module ( à faire les dernières semaines du projet).
- Finalisation du programme de contrôle des moteurs. Puisque nous avons décidé de piloter le tank avec un joystick, nous utilisons des coordonnées X-Y pour contrôler le sens de rotation des moteurs ainsi que leur vitesse de rotation. Cependant ce système a un problème, si la tension fournit au moteur est trop faible, le moteur ne tourne pas. (Régler Problèmes). Il faudrait ajouter un condensateur pour que les moteurs aient un peu de puissance au départ de leur rotation.


Fonction de contrôle des RPM des moteurs ainsi que leur sens de rotation selon la position du joystick

Fonction de mouvement des
moteurs

Fonction loop des moteurs


Mapping du joystick

Les différentes valeurs de PWMD ( Moteur Droit) et PWMG( Moteur Gauche) sont déterminées selon la position du joystick. Si le point est vers le haut alors le tank avance, s’il est à gauche, le tank tourne à gauche. Cependant Selon la position du point on doit associer une valeur entre 0 et 255 pour les PWM. Cela implique d’utiliser différentes formules pour appliquer la valeur adaptée aux PWM.

## Travail de la séance:

Durant cette séance j’ai continué la modélisation du tank et plus particulièrement de la plateforme qui servira à entreposer les différents composants du tank ( carte Arduino, pont en H, moteurs, etc…).
Au départ nous avions pensé à une plateforme de 400 mm x 200 mm mais cette dimension était trop grande, nous avons donc revu les dimensions à la baisse et on a désormais une plateforme de 250 mm x 150 mm, ce qui est plus raisonnable. Pour maintenir les moteurs en place j’ai modélisé des petites calles qui se visseront sur les moteurs. L’objectif, c’est de visser les moteurs sous la plaque pour avoir le maximum de place au-dessus. On pourra loger les ponts en H, la carte Arduino, ainsi que la batterie.


Plaque du châssis


Calle pour moteur

Dans un premier temps, il faut tester les pièces, j’ai donc voulu découper ces pièces dans des planches de bois de 3mm à l’aide de la découpeuse laser. J’ai dû exporter le fichier Onshape au format DXF et puis passer par Inskape pour désigner les parties à couper.


Fenêtre Inkscape


Le design du tank sera inspiré des chars Renault de la 1er Guerre Mondial, les FT-17. Ils sont petits et agiles, parfait pour notre projet.


Char FT-17


Aperçu du tank du model 3D du tank ( en cours)


Schéma du tank

Châssis en bois pour tank | Calles en bois pour soutenir les moteurs

Les calles en bois ne sont pas percées, impossible de faire passer des vis. Il faudra percer des trous aux endroits adaptés pour pouvoir soutenir les moteurs et faire passer les vis.

Il reste encore les roues à modéliser et le pied arrière à manufacturer. Les roues devront être fabriquer via impression 3D car il nous faudra des roues au diamètre et à la forme particulières. Pour le pied arrière, une version en bois est envisagée.

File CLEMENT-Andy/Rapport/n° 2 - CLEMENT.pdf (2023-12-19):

CLEMENT Andy | Polytech Nice-Sophia Peip2

## Rapport de Séance n°2

## (Semaine du 18 Décembre)

Pour régler le problème d’alimentation des moteurs, j’ai un dû modifier les branchements du pont en H. En effet sur le pont en H , il y a 2 entrées de courant. Une entrée (5 V) pour alimenter les portes logiques et une deuxième (12 V) pour alimenter les moteurs. Il fallait également enlever un jumper entre le 12V et le GND pour que tout fonctionne. Pour l’instant j’ai récupéré une alimentation externe qui me permet de faire mes tests moteurs (Alimentation récupérer dans la salle de TP). Elle délivre 5V pour les 2 moteurs DC mais devra être plus puissante en vue d’alimenter les autres composant du Tank ( Canon entre autres) . Il faudra se pencher sur une alimentation portable comme des piles ou encore une batterie de modélisme.


Schéma de montage pour
alimentation des moteurs


Une fois les branchements effectués, il me fallait coder le programme de contrôle du tank pour qu’il puisse avancer, reculer et tourner. Si au départ je pensai associer chaque action à un bouton de la manette de contrôle, j’ai trouvé plus pertinent de développer un contrôle via un joystick. Comme mentionné dans le cahier des charges, le contrôle du tank se fera à distance. On a décidé d’utiliser la communication via Bluetooth pour le contrôle. On utilise l’application Bluetooth Electronics pour contrôler l’appareil en utilisant le joystick virtuel.

On a donc reçut un module Bluetooth HC-05 pout le contrôle du véhicule. Il m’a fallu le configurer, cependant je n’ai pas réussi à communiquer avec lui dès l’étape d’initialisation. J’ai essayé de le faire fonctionner chez d'autres camarades mais impossibles de communiquer avec. J’en ai donc demandé un autre à la fin de la séance pour essayer de régler le problème. Ce problème devra être réglé durant les vacances de Noël pour éviter qu’il devienne handicapant.


Branchement du module
Bluetooth HC-05

Alimentation externe 5V

CLEMENT Andy | Polytech Nice-Sophia Peip2


Matériel reçu durant la séance:
- Module Bluetooth HC-05
- Alimentation 5V pour les moteurs
- Bread Board

Concernant le joystick, celui-ci renvoie des coordonnées d’un repère cartésien (x, y). Lors de la configuration du joystick, il est possible d’initialiser les dimensions du repère. On choisira de les étendre de 0 à 510 pour simplifier les calculs de conversions entre les coordonnées et la puissance à appliquer dans les moteurs ( les moteurs acceptent des puissances allant de 0 à 255). Cela reste à développer.

Code communicant avec
le module Bluetooth


Montage temporaire de
tous les éléments

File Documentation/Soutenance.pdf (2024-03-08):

Projet Arduino: The Destroyer

CLEMENT Andy / HADDOURY Hamza

# INTRODUCTION

Objectif:

-Objet mobile
-Contrôle à distance
-Utilisation simple et ludique

Cahier des charges:

-Tir de projectile ( Canon)
-Communication bluetooth
-Marche avant/ marche arrière/ virage
gauche/ virage droite
-Fonctionnement sur batterie

Fonctionnement général; Envoie des information par Bluetooth; Traitement par la carte arduino (Programme); Réaction des moteurs; Réception par des info par le HC-05

Conception (Châssis et roues); Châssis et mouvement:; -Placement des éléments dans le châssis; problèmes); Roue arrière; Roue avant; Capot; Châssis

-Imagination de la forme du tank ( Char FT-17)

-Modélisation des roues et des supports de roue -Conception via Onshape ( prévention des

# Conception (Canon)


Supports et chargeur :
- Imagination de supports ergonomiques.
- Modélisation et Impression d’un support pour les 2 moteurs, d’un chargeur (capacité : 5 balles) et d’une coque pour le canon.
- assemblage des pièces pour constituer le canon.

# Matériel nécessaires

- 1 Carte Arduino Mega
- 2 motoréducteurs à courant continue
- 2 ponts en H ( L298N)
- 1 module Blutooth HC-05
- 1 batterie Lithium-ion de 7V
- 3 servos moteurs- SG90 (Chargeur)
- 2 moteurs à faible couple-MABUCHI RS 280 ( lanceur de balle)

# branchement général


# Assemblage


Code; Programmation: - programmation fonctionnel: chaque fonction est relié à une action - contrôle des moteurs de direction.; Exemple de fonction
Demonstration

Thanks for listening

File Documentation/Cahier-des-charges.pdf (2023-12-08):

# Cahier des charges

# Objectif du projet

Concevoir et construire un tank télécommandé à l'aide d'une plateforme Arduino, intégrant la mobilité, la fonctionnalité de tir et une structure robuste.

## 1. Mobilité

### Branchement des Moteurs:

### Programmation du Mouvement:

## 2. Canon

### Orientation du Canon:

### Fonctionnalité de Tir:

## 3. Alimentation

Batterie:

## 4. Structure

Coque:

Chenille + Roue:

Phare:

Logement du Canon:

Logement de la Carte Arduino:

Intégrer deux moteurs pour les chenilles.

Programmer le mouvement du tank (avancer, reculer, tourner) à l'aide de la télécommande.

Intégrer un servo-moteur pour l'orientation du canon. Programmer le contrôle de l'orientation via la télécommande.

Intégrer un mécanisme de tir (par exemple, un lanceur de projectiles). Programmer le contrôle du tir via la télécommande.

Sélectionner une batterie adaptée pour alimenter le tank.
Intégrer un système de recharge ou un remplacement facile de la batterie.

Concevoir et construire une coque robuste pour protéger les composants internes.

Intégrer un système de chenilles robuste pour une mobilité optimale.

Intégrer des phares LED pour une meilleure visibilité dans des conditions de faible luminosité.

Intégrer un support solide pour le canon, permettant une orientation précise.

Prévoir un espace dédié et sécurisé pour la carte Arduino.

Logement de la Batterie:; 5. Commande à distance; **Note:**; besoins spécifiques du projet.

Ce cahier des charges est un guide général pour le moment et pourra être ajusté en fonction des

Concevoir un compartiment sécurisé pour la batterie, avec un accès facile pour la maintenance.

Associer le code du véhicule avec un moyen de contrôle à distance ( Par Bluetooth ou par RF)

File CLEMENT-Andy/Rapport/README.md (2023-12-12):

<center> Lieu où seront stockés tous les rapports de séances ( Avant 22h le jours suivant la séance). </center>

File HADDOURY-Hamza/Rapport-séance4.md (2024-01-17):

# Rapport de la Séance 4

**Date de la Séance: 15/01/2024**

**Objectifs de la Séance:**
- Modéliser la structure du canon.
- Modéliser les différentes pièces nécessaires.
- Concevoir un espace pour disposer les éléments électroniques tels que les moteurs, les roues, le pont en H et les câbles.

**Activités Réalisées:**

1. Modélisation de la base de la structure cylindrique du canon.
2. Création d'un espace en dessous de la structure pour accueillir le servo-moteur.
3. Modélisation et impression du support pour fixer le servo-moteur au tank.
   Texte alternatif

4. Assemblage en carton d'un support pour les moteurs avec un espace dédié entre les deux pour le projectile.

   Texte alternatif

5. Branchement du servo-moteur et tests pour s'assurer de son bon fonctionnement.

**Points Forts:**
- Réussite de l'assemblage en carton pour le support moteur avec un espace spécifique pour le projectile.
- Avancement dans la modélisation de la structure du canon.

**Points à Améliorer:**
- Nécessité de prendre en compte tous les détails, en particulier pour la fixation précise des éléments.
- Problème de la puissance variable du projectile en fonction de son introduction entre les moteurs.

**Problèmes Rencontrés:**
- La modélisation de la structure finale prend plus de temps que prévu.
- La force du projectile varie en fonction de son positionnement entre les moteurs.

**Plan d'Action pour la Prochaine Séance:**
1. Finaliser la modélisation de la structure du canon.
2. Trouver des solutions pour assurer une puissance de tir constante du projectile.
3. Examiner les détails de fixation des éléments électroniques pour une intégration optimale.
4. Planifier une séance de tests pour évaluer la performance globale du tank.

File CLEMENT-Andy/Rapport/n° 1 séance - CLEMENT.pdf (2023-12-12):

CLEMENT Andy | Polytech Nice-Sophia Peip2

## Rapport de Séance n°1

## (Semaine du 11 Décembre)

Au vu de l’ampleur du projet, j’ai rectifié mon planning pour qu’il soit plus cohérent

Pour cette première séance, nous avons pu prendre connaissance des pièces nécessaires au montage de notre tank. M’occupant principalement de l’armature du tank ainsi que de ses déplacements, j’ai reçu :

- 2 moteurs DC (FA-130) pour diriger le tank
- 1 pont en H pour les contrôler (et un de plus pour mon collègue) pour connecter les moteurs à la carte Arduino.


Moteurs DC (FA-130) | Pont en H

Ces moteurs m’ont été données sans raccord électrique, j’ai dû alors me rendre au FabLab pour raccorder mes moteurs à des fils électriques et ainsi faire les branchements. J’ai appris à faire mes premières soudures à l’étain.

Bien que les branchements soient sommaires, ils me permettent de tester les moteurs ainsi que de commencer à écrire le programme (pas encore terminé). Malheureusement j’ai eu un problème avec ma carte Arduino qui m’a ralenti mais qui a vite été réglée. De plus il semble que la puissance fournie par la carte Arduino ne permette pas de faire tourner les moteurs correctement, je devrais essayer avec une alimentation plus puissante.


Montage sommaire des moteurs

Voici une première version du code qui me permet seulement de tester les moteurs (Code reprit du cours sur les moteurs) :


Nous avons aussi cherché un modèle de chenille imprimable en 3D. Un auteur les propose sur un site mais il nous reste encore à déterminer les dimensions pour pouvoir envisager de lancer l’impression vue que cela prend du temps.


Exemple de chenilles imprimables en 3D

Cette première séance m’a permis de revoir l’ampleur du chantier et de me rendre compte du travail à accomplir.

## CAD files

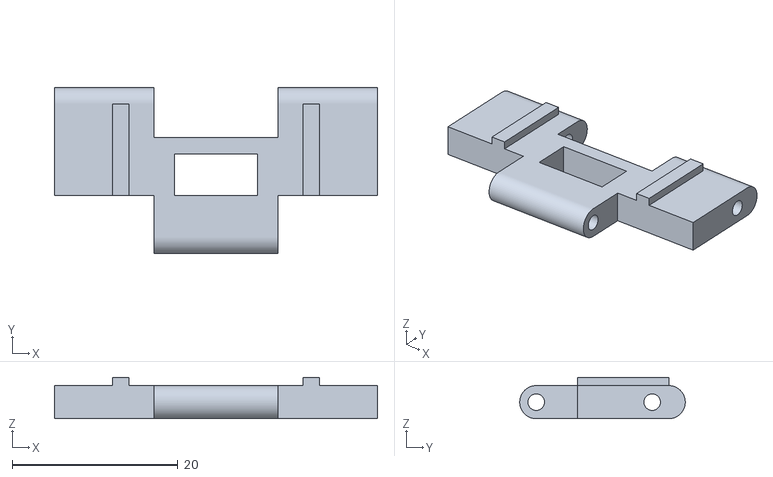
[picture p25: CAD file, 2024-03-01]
CLEMENT-Andy/Model-3D/Chenille/Maille chenille.stl
39.0 x 20.0 x 5.00

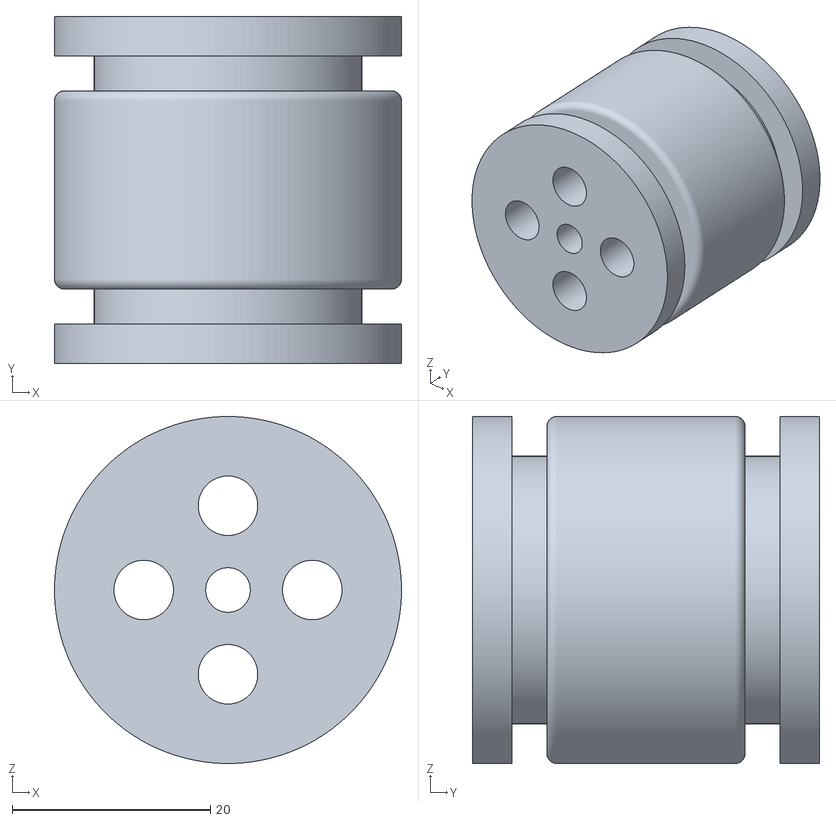
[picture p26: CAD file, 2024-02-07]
CLEMENT-Andy/Model-3D/Roue/Roue arrière/Roue arrière.stl
35.0 x 35.0 x 35.0

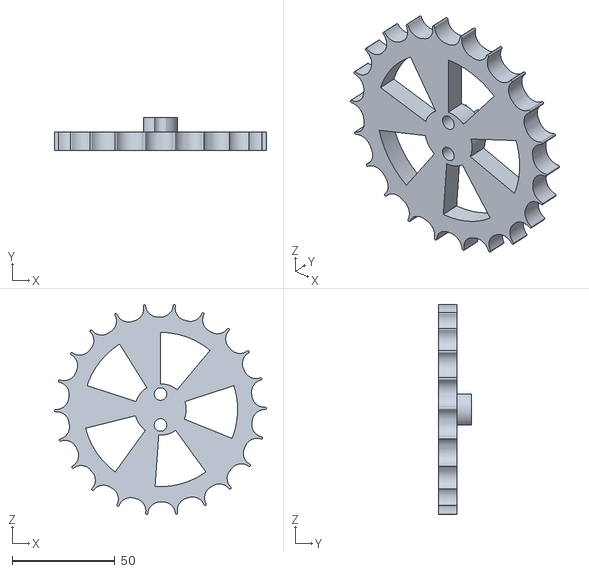
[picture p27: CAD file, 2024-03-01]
CLEMENT-Andy/Model-3D/Roue/Roue motrice (avant)/Roue-Motrice-partie2.stl
103.1 x 16.0 x 102.2

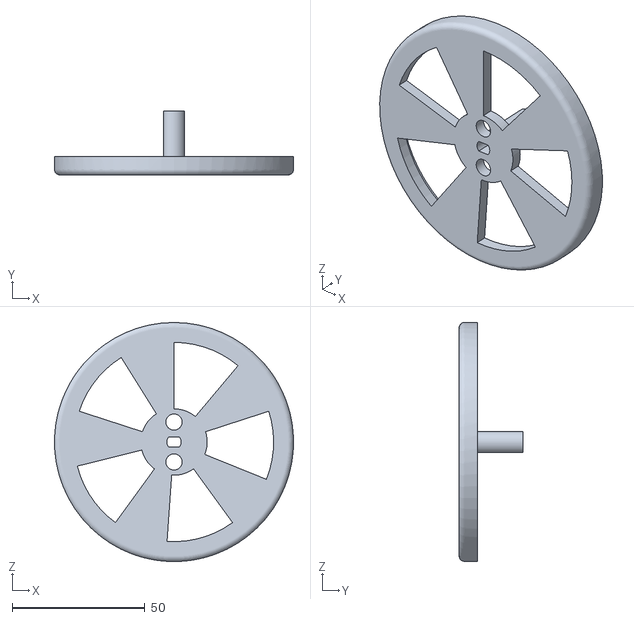
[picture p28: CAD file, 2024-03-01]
CLEMENT-Andy/Model-3D/Roue/Roue motrice (avant)/Roue-Motrice-partie1.stl
90.0 x 24.0 x 90.0

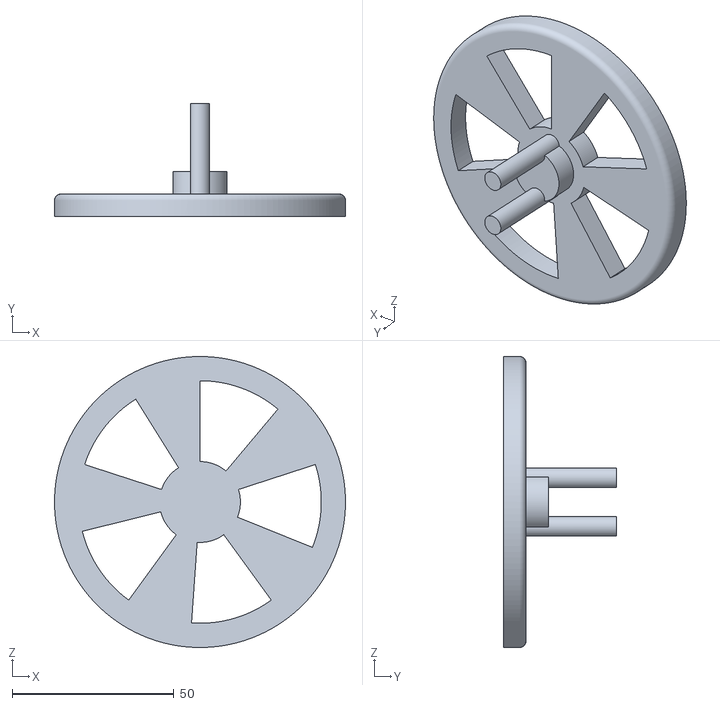
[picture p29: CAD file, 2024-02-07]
CLEMENT-Andy/Model-3D/Roue/Roue motrice (avant)/Roue-Motrice-partie3.stl
90.0 x 35.0 x 90.0

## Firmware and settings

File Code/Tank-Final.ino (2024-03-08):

#include <Servo.h>
#include<string.h>
#include<SoftwareSerial.h>
#define RX 50 // Broche 50 en tant que RX, à raccorder sur TX du HC-05
#define TX 51 // Broche 51 en tant que TX, à raccorder sur RX du HC-05
SoftwareSerial BlueT(RX,TX);
char caract;// Caractère relevé lors de la communication bluetooth

int power=255; //Puissance des moteurs de traction

//-- MOTEUR A (Avant Droit) --
int ENG=7; //Connecté à Arduino pin 7(sortie PWM)
int IN1=6; //Connecté à Arduino pin 6
int IN2=5; //Connecté à Arduino pin 5

//-- MOTEUR B (Avant Gauche) --
int END=2; //Connecté à Arduino pin 2(Sortie PWM)
int IN3=4; //Connecté à Arduino pin 4
int IN4=3; //Connecté à Arduino pin 3

const int enableMotor1 = 13;
const int motor1Input1 = 12;
const int motor1Input2 = 11;
const int enableMotor2 = 8;
const int motor2Input1 = 10;
const int motor2Input2 = 9;
const int servoPin1 = 42; // Broche pour le premier servo-moteur
const int servoPin2 = 40; // Broche pour le deuxième servo-moteur
const int servoPin3 = 41;

Servo myServo1; // Crée une instance de la classe Servo pour le premier servo-moteur
Servo myServo2; // Crée une instance de la classe Servo pour le deuxième servo-moteur
Servo myServo3;

// Fonction pour convertir un angle de -90 à 90 degrés en une valeur de 0 à 180 degrés
int mapAngle(int angle) {
  return map(angle, -90, 90, 0, 180);
}

void setup() {
  // Configuration des broches en sortie pour les moteurs
  pinMode(enableMotor1, OUTPUT);
  pinMode(motor1Input1, OUTPUT);
  pinMode(motor1Input2, OUTPUT);
  pinMode(enableMotor2, OUTPUT);
  pinMode(motor2Input1, OUTPUT);
  pinMode(motor2Input2, OUTPUT);

  pinMode(END,OUTPUT); // Configurer
  pinMode(ENG,OUTPUT); // les broches
  pinMode(IN1,OUTPUT); // comme sortie
  pinMode(IN2,OUTPUT);
  pinMode(IN3,OUTPUT);
  pinMode(IN4,OUTPUT);

  //moteurs à l'arrêt
  digitalWrite(END,LOW);
  digitalWrite(ENG,LOW);

  digitalWrite(END,LOW);
  digitalWrite(ENG,LOW);
  
  analogWrite(END,0); 
  analogWrite(ENG,0);

  // Configuration des broches pour les servo-moteurs
  myServo1.attach(servoPin1);
  myServo2.attach(servoPin2);
  //myServo3.attach(servoPin3);

  // Démarre la communication série
  Serial.begin(9600);
  //Début de la communication bluetooth
  BlueT.begin(9600);
 
}

void loop() {
  while (BlueT.available()) {
    caract = BlueT.read();
    Serial.println(caract);
    switch(caract){
      case 'A':
        se();
        break;
      case 'T':
        rotateServoClockwise(myServo3, 40);
        break;
      case 'G':
        rotateServoClockwise(myServo3,-40);;
        break;
      case 'Z':
        forward();
        break;
      case 'S':
        moveBack();
        break;
      case 'D':
        right();
        break;
      case 'Q':
        left();
        break;
      case '/':
        analogWrite(END,0); //la voiture s'arrête lorsque l'on appuie sur aucun bouton
        analogWrite(ENG,0);
        break;
    }
  }
}



//Fonction relatif au canon
void MotorsOn() {
  // Activation du moteur 1
  analogWrite(enableMotor2, 100);
  digitalWrite(motor1Input1, LOW);
  digitalWrite(motor1Input2, HIGH);

  // Activation du moteur 2
  analogWrite(enableMotor1, 100);
  digitalWrite(motor2Input1, LOW);
  digitalWrite(motor2Input2, HIGH);
}

void rotateServoClockwise(Servo servo, int angle) {
  servo.write(mapAngle(angle)); 
}

void MotorsOff(){
  Serial.println("yyyy");
  digitalWrite(enableMotor1, LOW);
  digitalWrite(enableMotor2, LOW);
}



// Code relatif au mouvement
void forward(){
  //Serial.println(caract);

   // Direction du Moteur A (Gauche)
  digitalWrite(IN1,HIGH);
  digitalWrite(IN2,LOW);
  // Direction du Moteur B (Droite)
  digitalWrite(IN3,HIGH);
  digitalWrite(IN4,LOW);

  analogWrite(END,power); //vitesse droit
  analogWrite(ENG,power); //vitesse gauche
}

void moveBack(){
  // Direction du Moteur A (Gauche)
  digitalWrite(IN1,LOW);
  digitalWrite(IN2,HIGH);
  // Direction du Moteur B (Droite)
  digitalWrite(IN3,LOW);
  digitalWrite(IN4,HIGH);

  analogWrite(END,power); //vitesse droit
  analogWrite(ENG,power); //vitesse gauche
}

void left(){
  // Direction du Moteur A (Gauche)
  digitalWrite(IN1,HIGH);
  digitalWrite(IN2,LOW);
  // Direction du Moteur B (Droite)
  digitalWrite(IN3,LOW);
  digitalWrite(IN4,HIGH);

  //analogWrite(END,power); //vitesse droit
  analogWrite(ENG,power); //vitesse gauche
}

void right(){
  // Direction du Moteur A (Gauche)
  digitalWrite(IN1,LOW);
  digitalWrite(IN2,HIGH);
  // Direction du Moteur B (Droite)
  digitalWrite(IN3,HIGH);
  digitalWrite(IN4,LOW);

  analogWrite(END,power); //vitesse droit
  //analogWrite(ENG,power); //vitesse gauche
}

void se(){
  MotorsOn();
  delay(450);
  rotateServoClockwise(myServo2, 15);
  delay(100);
  rotateServoClockwise(myServo1, 40);
  delay(150);
  rotateServoClockwise(myServo1, -40);
  delay(100);
  rotateServoClockwise(myServo2, -15);
  MotorsOff();
}

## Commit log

2023-12-10 Rename Cahier des charges.pdf to Cahier-des-charges.pdf
2023-12-10 Update README.md
    Ajout du lien vers le cahier des charges .
2023-12-10 Update and rename Rapport to Rapport des séances
2023-12-10 Rename Rapport des séances to Rapport-seances.md
2024-01-09 Rapport de la séance 3
2024-01-16 Rapport de séance 4
2024-02-10 Ajout du rapport de séance n°6
2024-02-27 Programme de controle du tank
